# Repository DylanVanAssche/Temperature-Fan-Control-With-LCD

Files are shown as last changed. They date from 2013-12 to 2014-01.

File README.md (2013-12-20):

Temperature Fan Control With LCD
================================

A fan controlled by a temperaturesensor and an Arduino. The current temperature (in °C) and fanpower (in %) is shown on a LCD display.

Produced by Dylan Van Assche (2013). I'm not responsible for any damage to your stuff!

Libraries for EAGLE: 
* http://www.faludi.com/2008/10/07/arduino-avr-library-for-eagle-layout-editor/
* https://github.com/zumbik/Eagle-Libraries/blob/master/lm35.lbr

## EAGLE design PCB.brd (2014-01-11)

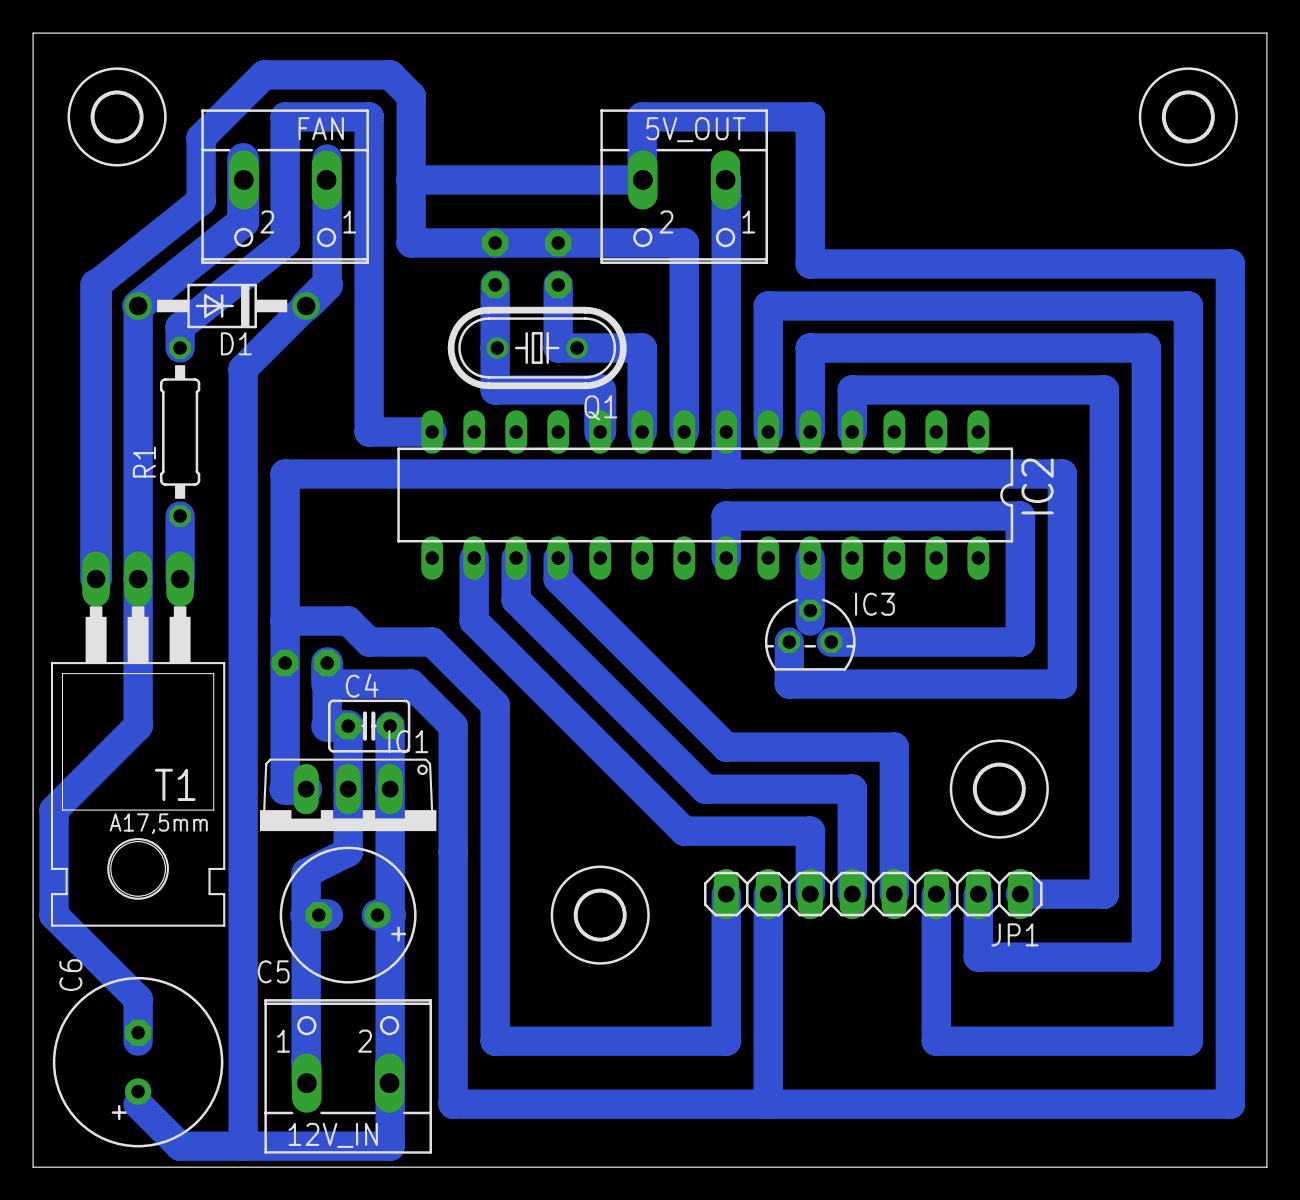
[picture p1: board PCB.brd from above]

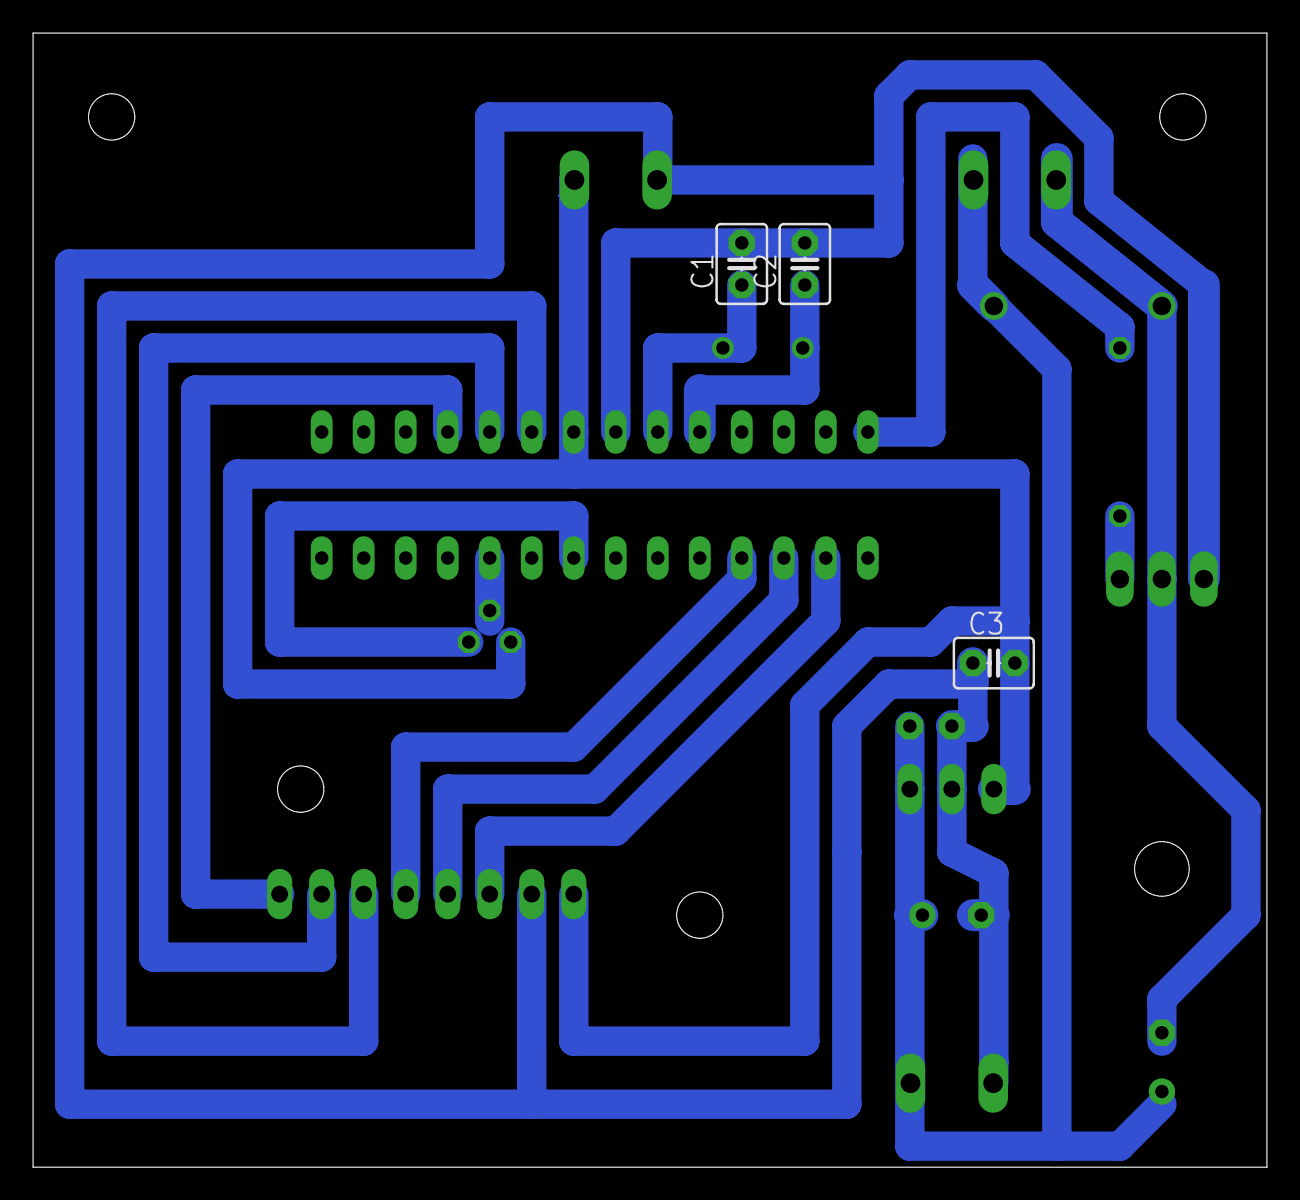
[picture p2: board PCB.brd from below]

Board: 2 copper layers, 74.6 x 68.6 mm, 21 parts (3 on the bottom side), 16 nets.

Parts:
5V_OUT, 12V_IN: W237-102
C1, C2: 22 pF; C2.5-3
C3, C4: 100 nF; C2.5-3
C5: 1000 uF; E3,5-8
C6: 2200uF; E3,5-10
D1: 1N4004; DO41-10
FAN: W237-102
H1, H2, H3, H4: MOUNT-HOLE2.8; 2,8
IC1: 7805TV; TO220V
IC2: ATMEGA168-PU; DIL28-3
IC3: LM35CZ; TO92
JP1: LCD; 1X08
Q1: HC49U-V
R1: 0207/10
T1: TIP122; TO220

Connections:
GND: 5V_OUT.2, C1.2, C2.2, IC2.8, IC2.22, IC3.3, JP1.7, T1.3
unnamed: C1.1, IC2.9, Q1.1
unnamed: IC2.16, JP1.6
unnamed: C6.-, D1.A, FAN.2, T1.2
unnamed: C2.1, IC2.10, Q1.2
unnamed: 12V_IN.1, C3.1, C4.1, C5.-, IC1.2
unnamed: IC2.4, JP1.1
unnamed: IC2.5, JP1.2
unnamed: IC2.6, JP1.3
unnamed: R1.1, T1.1
unnamed: IC2.17, JP1.5
unnamed: IC2.18, JP1.4
unnamed: IC2.14, R1.2
unnamed: IC2.24, IC3.2
unnamed: 12V_IN.2, C4.2, C5.+, C6.+, D1.C, FAN.1, IC1.1
VCC: 5V_OUT.1, C3.2, IC1.3, IC2.7, IC3.1, JP1.8

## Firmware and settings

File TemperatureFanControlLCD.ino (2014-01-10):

/*

 ******************************************
 *                                        *
 *--> TEMPERATURE FAN CONTROL WITH LCD <--*
 *                                        *
 *               V 1.0.1 RC               *
 ******************************************
 
 (c) Dylan Van Assche, you can use this sketch for free! It's opensource :)
 */

#include <SoftPWM_timer.h>
#include <SoftPWM.h>
#include <LiquidCrystal.h>
#include <TimedAction.h>

// Defines the pins for the LCD screen.
LiquidCrystal lcd(10, 11, 12, 4, 3, 2);

// Basic declarations.
int temperature    =    0;
int tempsensor     =   A1;
int fanpower       =    0;
int fan            =    8;

// Set up the LCD check timer.
TimedAction Update =  TimedAction(100,UpdateLCD);

void setup() 
{

  // Set up the LCD and some basic information on the LCD:
  lcd.begin(16, 2);
  lcd.clear();
  lcd.setCursor(0,0);
  lcd.print("Power:");
  lcd.setCursor(0,1);
  lcd.print("Temp.:");

  // Set up the SoftPWM library, with this library it doesn't make a difference if your pin is connected to a PWM-pin or not.
  SoftPWMBegin();
  SoftPWMSet(fan, 0);
  SoftPWMSetFadeTime(fan, 1000, 1000);

}

void loop() 
{

  // Check the timer during the loop.  
  Update.check(); 

}

// The LCD update function, it updates the information on the LCD display and controls the fan at the same time.
void UpdateLCD()
{

  // Converte analogRead to °C
  temperature = (5.0 * analogRead(tempsensor) * 100.0) / 1024;

  // Temperature on LCD.
  lcd.setCursor(10,1);
  lcd.print(temperature); 
  lcd.setCursor(13,1);
  lcd.print((char)223);
  lcd.setCursor(14,1);
  lcd.print("C");

  // Start the fans when the temperature reach 27 degrees.
  if(temperature >= 24)
  {
    fanpower = map(analogRead(tempsensor),35,140,15,100);
    lcd.setCursor(10,0);
    lcd.print(fanpower); 
    lcd.setCursor(13,0); 
    lcd.print("%"); 
    SoftPWMSetPercent(fan, fanpower);
  }
  else
  {
    lcd.setCursor(10,0); 
    lcd.print("0 ");  
    lcd.setCursor(13,0); 
    lcd.print("%"); 
    SoftPWMSetPercent(fan, 0);
  }

}

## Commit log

2013-12-13 TemperatureFanControlLCD V1.0.1 RC
    The first stable release. Tested on an Arduino UNO.
2013-12-20 EAGLE file for the PCB of this project
    [PCB.brd]
2013-12-20 Extra information!
    For this board I used the Arduino library for EAGLE. You can find it also in this repository.
    [PCB.brd]
2013-12-21 Update V1.1
    Bugfix: 7805 voltage regulator wiring.
    [Schematic.sch]
2014-01-11 Decoupling capacitor added and resistor
    Decoupling capacitor added for driving higher current without noise.
    [PCB.brd]
2014-01-11 Update V1.2
    Decoupling capacitor + resistor
    [Schematic.sch]
